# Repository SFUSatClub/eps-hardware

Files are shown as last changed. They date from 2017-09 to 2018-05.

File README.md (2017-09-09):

# CubeSat Electrical Power Subsystem
KiCad project of the cubesat electrical power subsystem test article in preparation for the Canadian Satellite Design Challenge

This repository uses the SFU Satellite Team's KiCad component library as a submodule.
To start working on the repository:

```
1. Open the git shell
2. Navigate to the directory you wish to place the repository inside
3. git clone --recursive "https://github.com/SFUSatClub/eps-hardware.git"
4. cd .\eps-hardware\KiCad-Lib\
5. git checkout master
```

If you modify either the component schematic or footprint libraries you must push those changes to the SFUSatClub/KiCad-Lib repository.

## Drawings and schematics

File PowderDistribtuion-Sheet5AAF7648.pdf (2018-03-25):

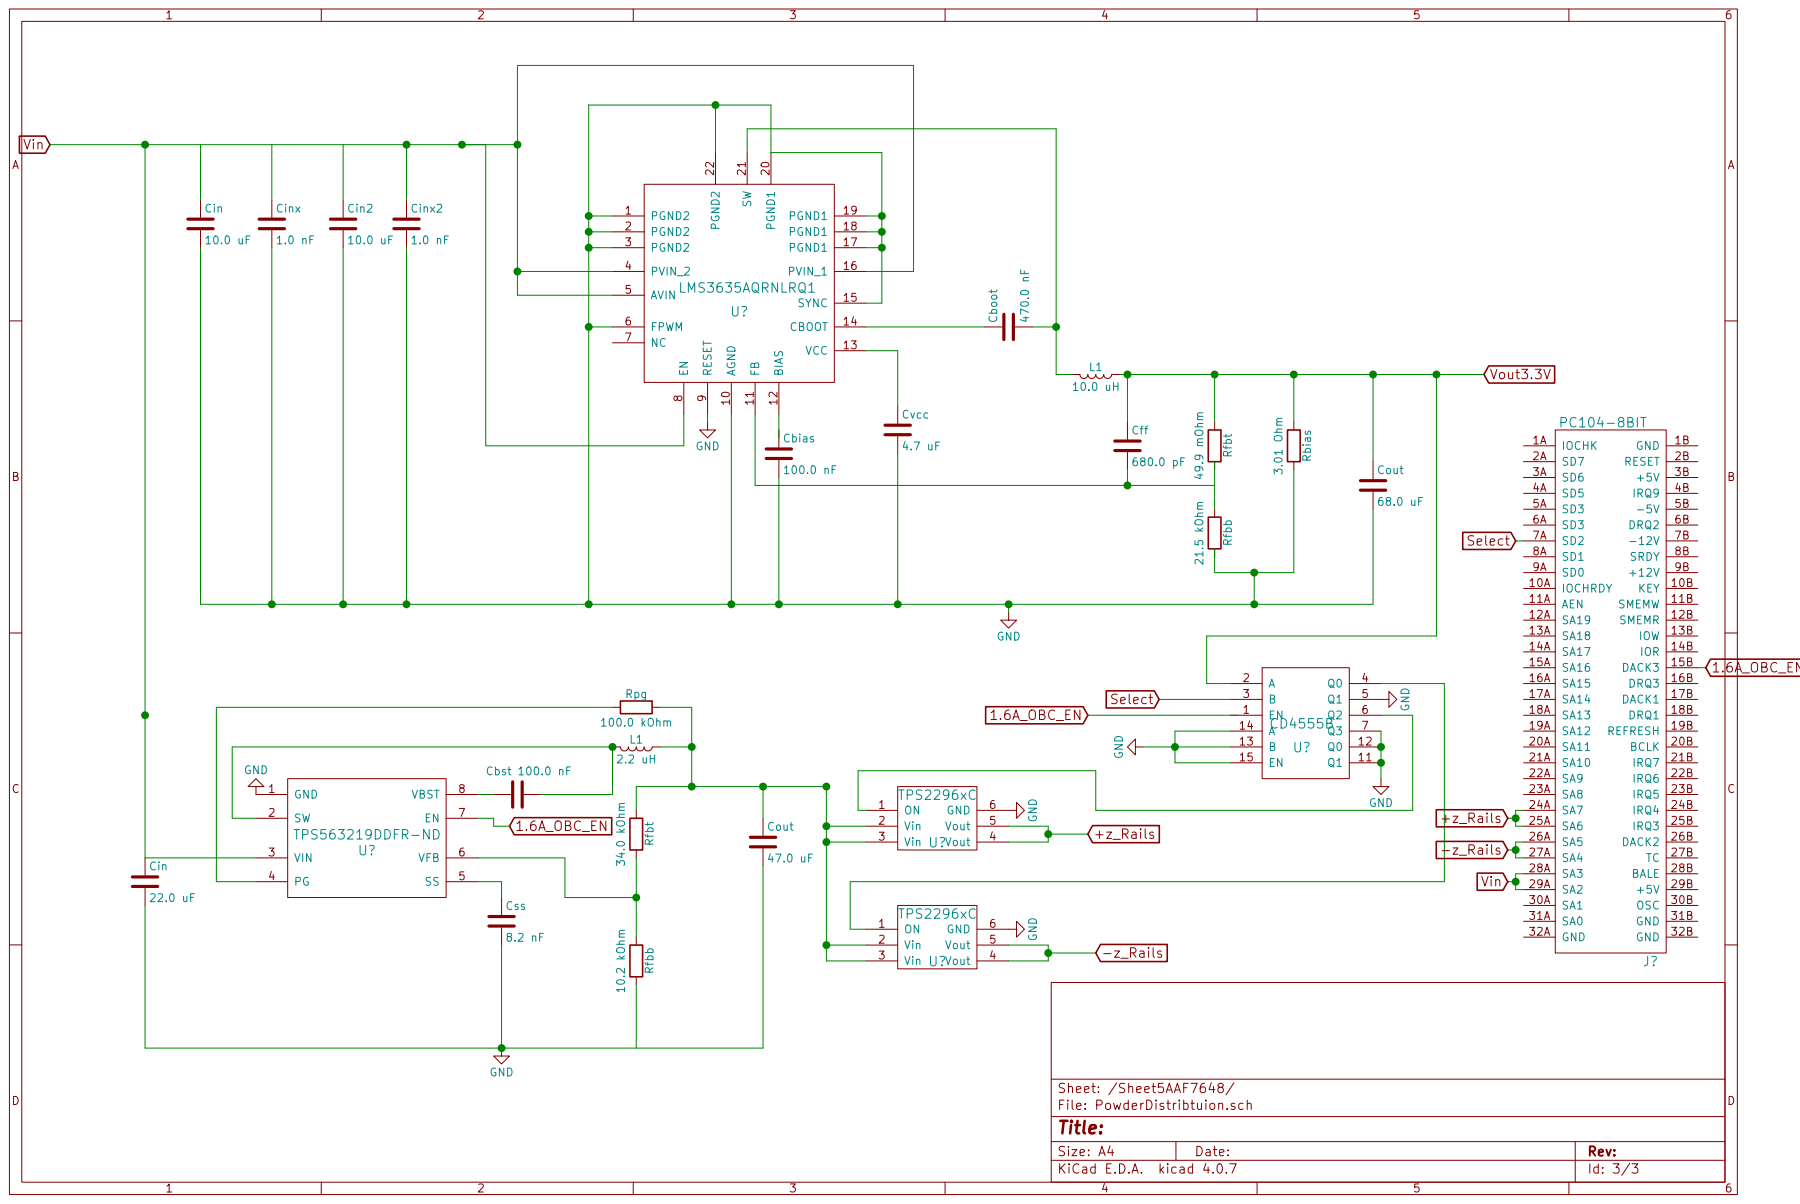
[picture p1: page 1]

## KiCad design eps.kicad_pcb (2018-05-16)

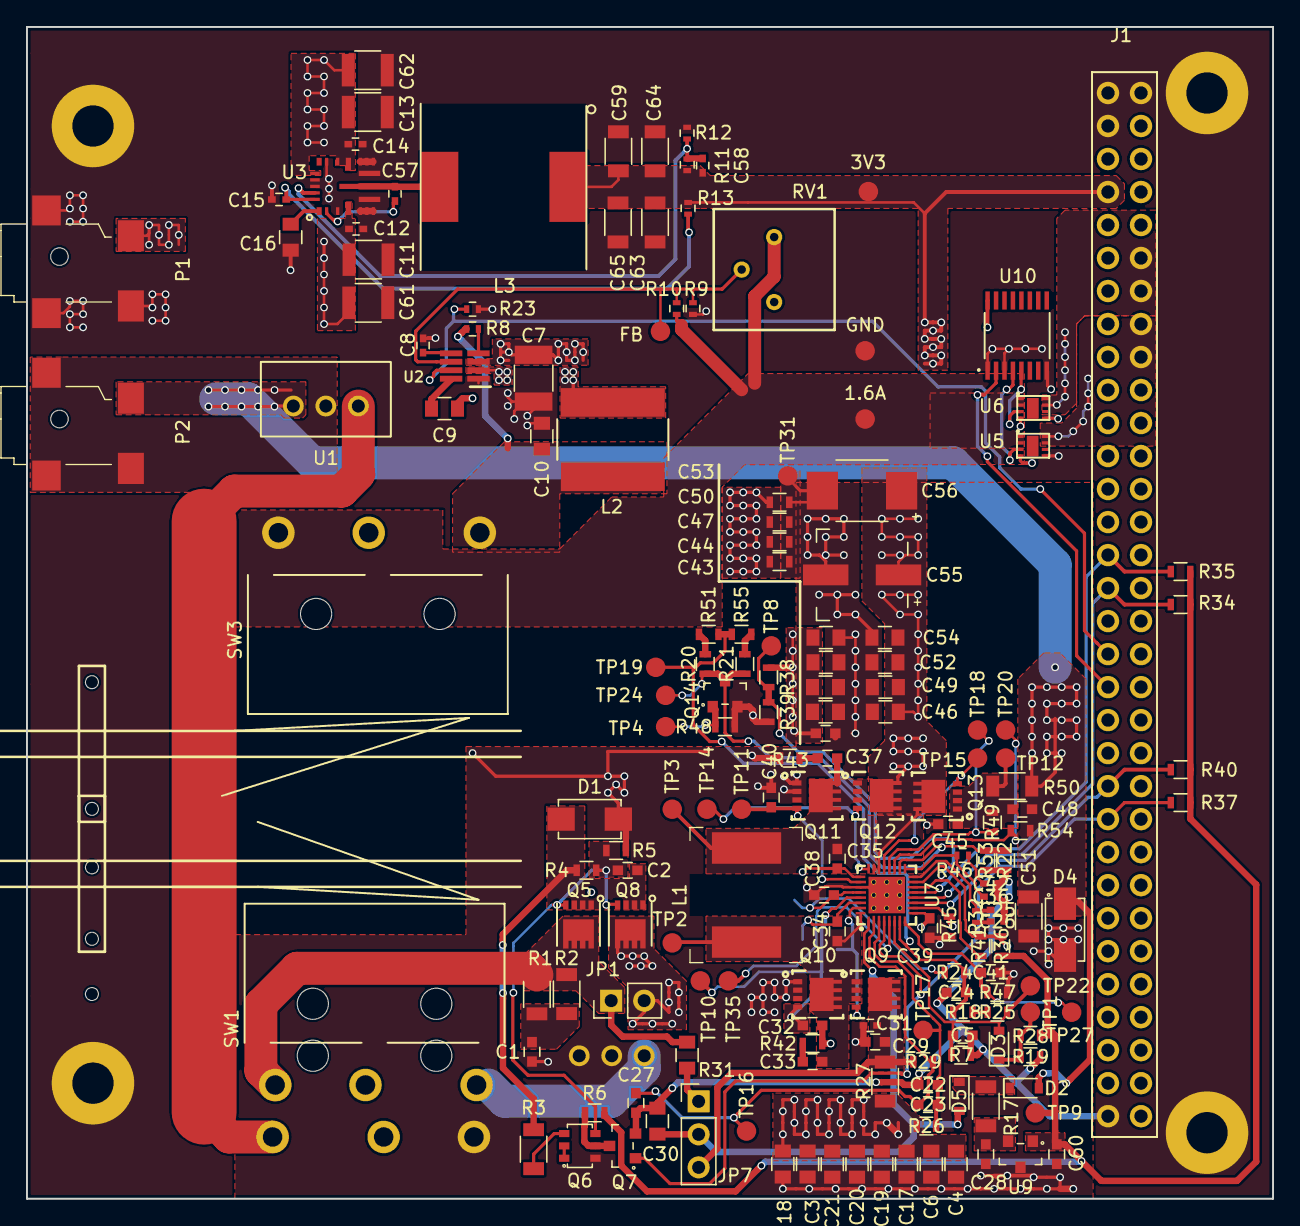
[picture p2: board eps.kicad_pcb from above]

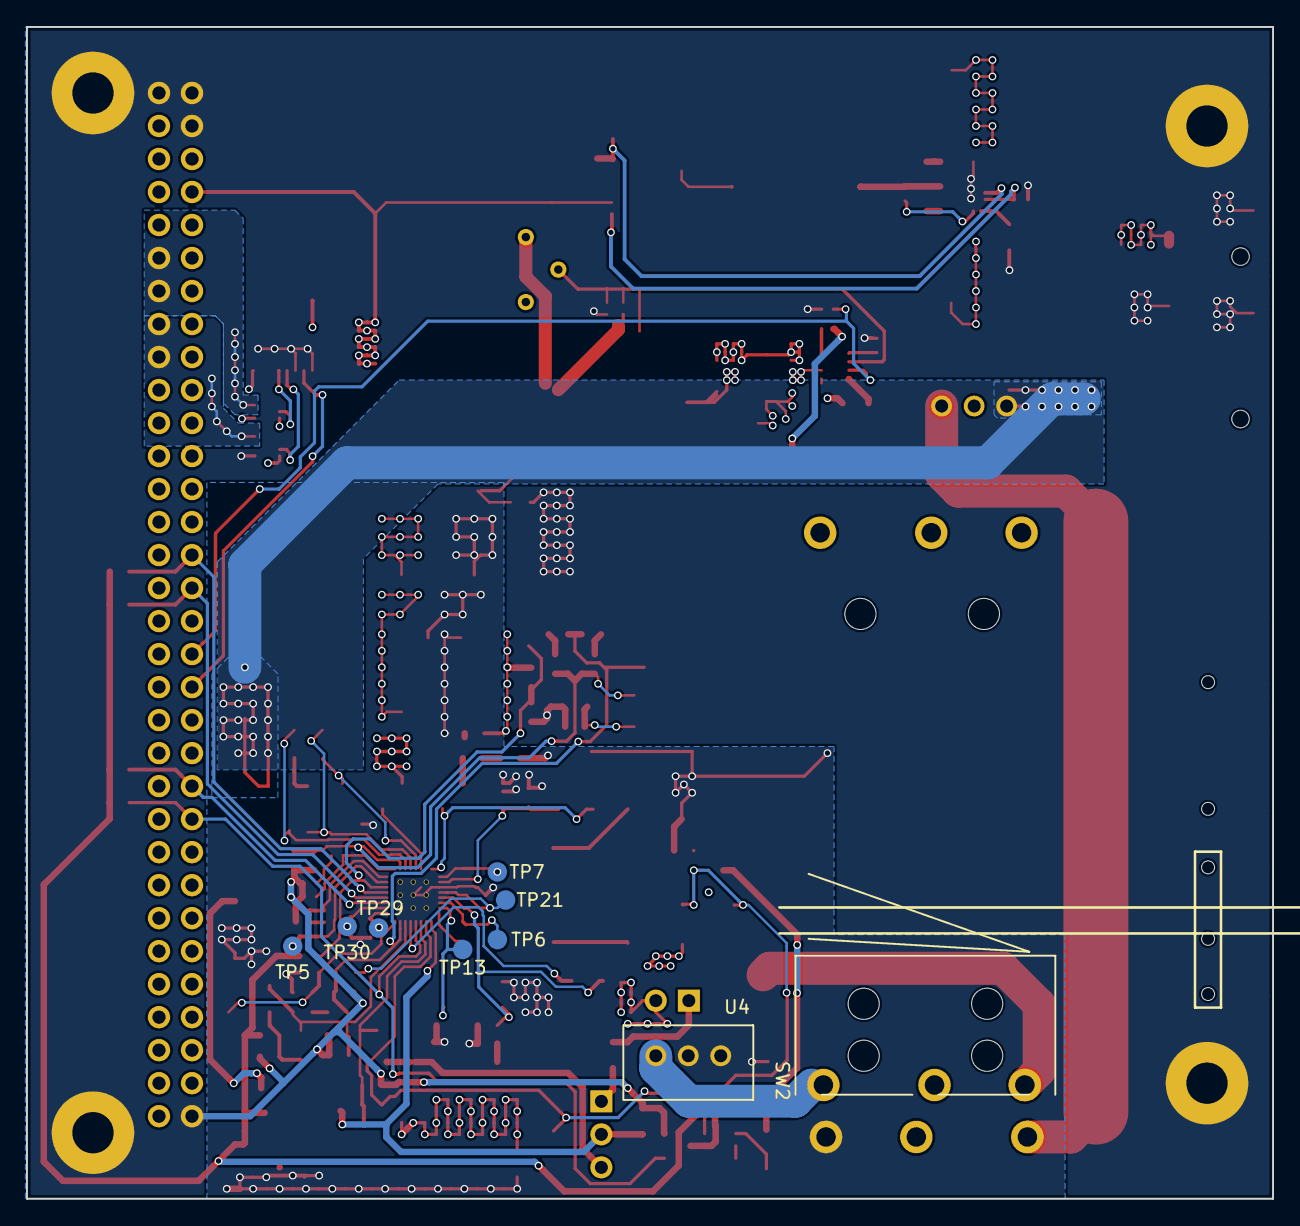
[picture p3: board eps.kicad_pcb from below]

Board: 4 copper layers, 95.9 x 90.2 mm, 189 parts (9 on the bottom side), 80 nets.

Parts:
C1, C24: 1u0; C_0603
C2, C28, C48, C60: 100n0; C_0603
C3, C18, C53, C54: DNP; C_0805
C4, C6, C17, C19, C20, C21: 10u0; C_0805
C5, C39, C41: 100p0; C_0603
C7: 22.0 uF; C_1210
C8: 8.2 nF; C_0402
C9: 100.0 nF; C_0805
C10: 47.0 uF; C_0805
C11, C13, C61, C62: 10.0 uF; C_1210
C12, C14: 1.0 nF; C_0402
C15: 100.0 nF; C_0402
C16: 4.7 uF; C_0805
C22, C27: 33n0; C_0603
C23, C33, C37, C43: DNP; C_0603
C25: 33p0; C_0402
C26: 1n8; C_0402
C29: 10n0; C_0603
C30: 470n0; C_0805
C31: 1n0; C_0402
C32, C40: 150p; C_0603
C34, C35: 47n; C_0603
C36: 15p0; C_0402
C38: 2u2; C_0603
C42: 680p; C_0402
C44, C46, C47, C49, C50, C52: 10u; C_0805
C45: 1u; C_0603
C51: 10u0; C_1206
C55: DNP; C_ALUM_2626
C56: 47u; C_TANT_2917
C57: 470.0 nF; C_0402
C58: 680.0 pF; C_0402
C59, C63, C64, C65: 68.0 uF; C_1206
D1: SMAJ26CA; DO-214AC-BI
D2, D3, D5: BAT54HT1G; SOD-323
D4: B220A-13-F; DO-214AC
J1: PC104-8BIT; PC104-8bit
J2, J3, J4, J5: PC104PTH
JP1: Conn_01x02; Socket_Strip_Straight_1x02_Pitch2.54mm
JP7: Conn_01x03; Socket_Strip_Straight_1x03_Pitch2.54mm
L1: 2u2; L_8030
L2: 2.2 uH; SRN8040-2R2Y
L3: 10.0 uH; L_7447709100
P1, P2: 3pin-DC-power; PJ-028-SMT-TR-3pin-DC-jack
Q5, Q8: DMP3035SFG-7; POWERDI3333-8
Q6: DCX124EK-7-F; SC-74
Q7, Q14: 2N7002ET1G; SOT-23-3
Q9, Q10, Q11, Q12: CSD17551Q3A; 8-PowerWDFN
Q13: CSD25402Q3A; 8-PowerWDFN
R1, R2: 3R9; R_1206
R3, R17: 10R0; R_1206
R4, R53: 100k0; R_0603
R5: 20k0; R_0603
R6, R36, R37, R40: 10k0; R_0603
R7: 220k0; R_0603
R8: 100k; R_0402
R9: DNP; R_0402
R10: 1k62; R_0402
R11: 49.9 kOhm; R_0402
R12: 21.5 kOhm; R_0402
R13: 3.01 Ohm; R_0402
R14, R15, R16, R19, R21, R22, R34, R35, R38, R42, R43, R44: DNP; R_0603
R18, R20: 0R; R_0603
R23: 1K; R_0402
R24, R49, R54: 10R0; R_0603
R25, R28: 383k0; R_0603
R26, R29: 4R99; R_0603
R27, R50: 10m0; R_1206
R31: 1R0; R_0805
R32: 40k2; R_0402
R39, R48: 300k0; R_0603
R41: 2M0; R_0603
R45: 30k1; R_0603
R46: 10k0; R_0402
R47: 137k0; R_0603
R51: 120k0; R_0603
R55: 64k9; R_0603
RV1: CT6EP103
SW1, SW2: LIMIT_SWITCH; SS-3GLPD-L
SW3: LIMIT_SWITCH; SS-3GLPD-R
TP1, TP2, TP3, TP4, TP5, TP6, TP7, TP8, TP9, TP10, TP11, TP12, TP13, TP14, TP15, TP16, TP17, TP18, TP19, TP20, TP21, TP22, TP23, TP24, TP25, TP27, TP28, TP29, TP30, TP31, TP33, TP35: TEST; Measurement_Point_Round-SMD-Pad_Small
U1, U4: B3B-XH-A(LF)(SN); B3B-XH-A
U2: TPS563219DDFR-ND; SOT-23-8
U3: LMS3635AQRNLRQ1; LMS3635AQRNLTQ1
U5, U6: TPS22967
U7: bq25703arsnt; S-PWQFN-N32
U9: LM3480; SOT-23-3
U10: CD4555BPWR; TSSOP-16

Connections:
/1.6A_Regulator_PDB/1.6A: C10.1, L2.1, R8.2, SW3.COM
/1.6A_Regulator_PDB/PG: R8.1, U2.4
/1.6A_Regulator_PDB/SW: C9.1, L2.2, U2.2
/1.6A_Regulator_PDB/VBOOT: C9.2, U2.8
/3.3V_Regulator_PDB/BIAS: C15.1, R13.2, U3.22
/3.3V_Regulator_PDB/CBOOT: C57.1, U3.2
/3.3V_Regulator_PDB/FB: C58.2, R11.2, R12.1, U3.21
/3.3V_Regulator_PDB/SW: C57.2, L3.2, U3.9
/3.3V_Regulator_PDB/VCC: C16.1, U3.1
/3V3: C58.1, C59.1, C63.1, C64.1, C65.1, J1.3B, J1.29B, L3.1, R11.1, R13.1, TP28.1, U5.4, U6.4, U10.16
/+z_rail: J1.24A, J1.25A, U5.7, U5.8
/-z_rail: J1.26A, J1.27A, U6.7, U6.8
/BMS/3V3: C60.1, R6.1, R28.1, R34.1, R35.1, R36.1, R37.1, R40.1, TP9.1, U9.1
/BMS/ACN: C23.2, C27.1, R29.2, TP16.1, U7.2
/BMS/ACP: C22.1, C23.1, R26.2, TP17.1, U7.3
/BMS/CELL_control: Q14.1, R48.2, TP4.1
/BMS/COMP2: C36.1, R46.1, U7.17
/BMS/HIDRV1: Q9.4, TP13.1, U7.31
/BMS/HIDRV2: Q12.4, TP14.1, U7.24
/BMS/ILIM_HIZ: C5.1, D3.1, R7.1, R25.1, TP22.1, U7.6
/BMS/ILIM_control: D3.2, R19.1, R28.2, TP1.1
/BMS/LODRV1: C32.1, Q10.4, TP10.1, U7.29
/BMS/LODRV2: C40.1, Q11.4, TP11.1, U7.26
/BMS/REGN: C38.1, R24.1, TP21.1, U7.28
/BMS/SRN: R54.2, TP20.1, U7.19
/BMS/SRP: R49.2, TP18.1, U7.20
/BMS/SW1: C33.1, C34.1, L1.1, Q9.1, Q9.2, Q9.3, Q10.5, Q10.6, Q10.7, Q10.8, Q10.9, TP2.1, U7.32
/BMS/SW2: C35.1, C37.1, L1.2, Q11.5, Q11.6, Q11.7, Q11.8, Q11.9, Q12.1, Q12.2, Q12.3, TP3.1, U7.23
/BMS/VBUS: C30.1, D5.1, JP7.2, U7.1
/BMS/VDDA: C24.1, R18.1, R24.2, R51.2, R55.2, TP19.1, U7.7
/BMS/VIN+: JP1.1, Q5.5, Q5.6, Q5.7, Q5.8, Q5.9, R1.1, R2.1, R31.2, SW1.NC
/CHG_OK: J1.10B, Q7.1, R37.2, U7.4
/DPL_EN: J1.15B, R23.1, U2.7
/DPL_SEL: J1.14B, U10.2
/FB: R9.2, R10.1, RV1.2, TP23.1, U2.6
/PowerDistributionDeploymentControl/1.6A: R9.1, RV1.1, SW3.NC, TP25.1, U5.1, U5.2, U6.1, U6.2
/PowerDistributionDeploymentControl/on+z: U5.3, U10.4
/PowerDistributionDeploymentControl/on-z: U6.3, U10.5
/SCL: J1.18B, R35.2, U7.13
/SDA: J1.17B, R34.2, U7.12
/VSYS_RETURN: C7.1, C11.1, C12.1, C13.1, C14.1, C61.1, C62.1, J1.28A, J1.29A, P1.1, U2.3, U3.4, U3.14, U3.15, U3.18
/VSYS_UP: C43.1, C44.1, C46.1, C47.1, C49.1, C50.1, C52.1, C53.1, C54.1, C55.1, C56.1, J1.30A, J1.31A, Q12.5, Q12.6, Q12.7, Q12.8, Q12.9, Q13.5, Q13.6, Q13.7, Q13.8, Q13.9, R38.1, U7.22
/Vin_Solar: SW1.COM, U4.3
/pack+: C48.2, C51.1, D2.1, D4.2, P2.1, R50.2, R54.1, U1.1
/pack-: P2.2, P2.3, U1.2
/return: SW2.COM, U1.3
/~PROCHP: J1.11B, R40.2, U7.11
GND: C5.2, C7.2, C8.2, C10.2, C11.2, C12.2, C13.2, C14.2, C15.2, C16.2, C22.2, C24.2, C25.1, C26.1, C27.2, C30.2, C36.2, C42.2, C59.2, C61.2, C62.2, C63.2, C64.2, C65.2, J1.1B, J1.31B, J1.32A, J1.32B, J2.1, J3.1, J4.1, J5.1, P1.2, P1.3, Q7.2, Q14.2, R7.2, R10.2, R12.2, R14.2, R15.2, R16.2, R19.2, R22.2, R23.2, R39.2, R44.2, R48.1, R53.1, TP33.1, U2.1, U3.3, U3.5, U3.6, U3.7, U3.8, U3.10, U3.11, U3.12, U3.13, U3.16, U3.19, U3.20, U5.5, U6.5, U10.1, U10.3, U10.8
GNDPWR: C1.2, C3.2, C4.2, C6.2, C17.2, C18.2, C19.2, C20.2, C21.2, C28.2, C29.2, C31.2, C32.2, C38.2, C39.2, C40.2, C41.2, C43.2, C44.2, C45.2, C46.2, C47.2, C49.2, C50.2, C51.2, C52.2, C53.2, C54.2, C55.2, C56.2, C60.2, D1.2, D4.1, Q6.6, Q10.1, Q10.2, Q10.3, Q11.1, Q11.2, Q11.3, R5.2, R14.1, R15.1, R16.1, R42.2, R43.2, R44.1, R45.1, R47.1, SW2.NC, TP31.1, U4.1, U4.2, U7.27, U7.33, U9.3
unnamed: C1.1, R1.2, R2.2
unnamed: C2.1, D1.1, Q5.1, Q5.2, Q5.3, Q8.1, Q8.2, Q8.3, R3.1, R4.1
unnamed: C2.2, Q5.4, Q6.4, Q8.4, R4.2, R5.1
unnamed: C8.1, U2.5
unnamed: C3.1, C4.1, C6.1, C17.1, C18.1, C19.1, C20.1, C21.1, JP1.2, Q8.5, Q8.6, Q8.7, Q8.8, Q8.9, R26.1, R27.1
unnamed: C25.2, R32.2, U7.16
unnamed: C26.2, R32.1
unnamed: C28.1, R17.2, U9.2
unnamed: C29.1, C31.1, JP7.3, Q9.5, Q9.6, Q9.7, Q9.8, Q9.9, R27.2, R29.1
unnamed: C33.2, R42.1
unnamed: C34.2, TP6.1, U7.30
unnamed: C35.2, TP7.1, U7.25
unnamed: C37.2, R43.1
unnamed: C39.1, TP29.1, U7.9
unnamed: C41.1, R47.2, TP27.1, U7.8
unnamed: C42.1, R46.2
unnamed: C45.1, C48.1, Q13.1, Q13.2, Q13.3, R49.1, R50.1, TP12.1
unnamed: D2.2, D5.2, R17.1
unnamed: JP7.1, R31.1
unnamed: Q6.1, Q6.2
unnamed: Q6.3, R3.2
unnamed: Q6.5, Q7.3, R6.2
unnamed: Q13.4, TP15.1, U7.21
unnamed: Q14.3, R20.2, R21.2, R22.1, R53.2, TP24.1, U7.18
unnamed: R18.2, R25.2
unnamed: R20.1, R51.1
unnamed: R21.1, R55.1
unnamed: R36.2, R41.1, TP5.1, U7.15
unnamed: R38.2, R39.1, R41.2, TP8.1, U7.14
unnamed: R45.2, TP30.1, U7.10
unnamed: TP35.1, U7.5

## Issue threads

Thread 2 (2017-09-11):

CubeSat side panel naming

TobiNakamura, 2017-09-11:
There are 4 solar battery charger schematics (MPPT_#) each numbered as 1,2,3,4. This name should be changed so that they are more descriptive of cubesat side. Something like port, starboard, topside, bottomside?

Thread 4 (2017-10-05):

Add Pull-before flight and deployment pins

TobiNakamura, 2017-10-05:
Series switches need to be placed to disconnect all solar cells and batteries.

TobiNakamura, 2018-02-07:
RBF needs to disconnect battery from ground and battery to load. Deployment pins are in series with RBF. The umbilical DC jack will need to use the jack switch feature to connect the battery with regulators while the RBF and/or deployment switches are engaged.

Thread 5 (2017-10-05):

bq40z50-R1 EOL

TobiNakamura, 2017-10-05:
confirm that bq40z50-R2 is a direct replacement: pin compatible, function near identical, performance near identical.

Alenux55, 2018-01-23:
This is getting replaced with [bq25703arsnt](https://www.digikey.ca/product-detail/en/texas-instruments/BQ25703ARSNT/296-46956-1-ND/7400157), is that correct?

TobiNakamura, 2018-01-24:
bq40z50-R2 is also being replaced by bq25703arsnt as @Alenux55 has noted.

Closed 2018-01-24.

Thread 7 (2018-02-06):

Battery Temp Sensing

TobiNakamura, 2018-02-06:
Need a thermal couple or similar on the batteries. OBC still has available I2C that could be used.

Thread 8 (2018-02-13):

New BMS, Mosfet symbol mismatch

Michael-Graves, 2018-02-13:
The schematic symbol for CSD25402Q3A is different from that of the datasheet.

On the datasheet (http://www.ti.com/lit/ds/symlink/csd25402q3a.pdf), the source is connected to the arrow while in our schematic the drain is connected to the arrow.

Michael-Graves, 2018-03-31:
The pin numbering is correct just the S and D labels are swapped

Closed 2018-05-04.

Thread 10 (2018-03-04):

Fix VSYS pin on BMS

Alenux55, 2018-03-04:
Currently, VSYS is connected to ground; obviously it should be connected to VSYS:

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

Alenux55, 2018-09-16:
This looks good to me now:
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

Closed 2018-09-16.

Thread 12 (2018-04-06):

SER2915L-103KL Footprint Issue

HarrisonHandley, 2018-04-06:
The downloaded footprint from Digikey for SER2915L-103KL Inductor doesn't agree exactly with the footprint layout in the datasheet. http://www.ti.com/lit/ds/symlink/cd4555b.pdf

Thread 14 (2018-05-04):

Power Mosfet footprints/netlists need to connect Pad 9 with pads 5-8

Michael-Graves, 2018-05-04:
The layout shouldn't need to be updated as fills are already in place, just need the netlists to be updated

Closed 2018-05-04.

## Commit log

2017-09-04 MPPT schematic complete. Following ST app note AN3319 section 5.
    [eps.sch]
2017-09-11 created MPPT hierarchical sheet
    [eps.sch, mppt.sch]
2017-09-11 added hierarchical sheet for BMS
    [bms.sch, eps.sch, mppt.sch]
2017-09-11 copied MPPT section for each of 4 side panels. The name for these 4 panels should be more descriptive
    [bms.sch, eps.sch, mppt.sch]
2017-09-12 overvoltage protection, charging/discharging fets, coloumb counter filter schematics complete. What should the secondary overvoltage output trigger? How should the MPPT output connect to the battery 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
    [bms.sch, eps.sch, mppt.sch]
2018-01-23 Started adding BQ25703ARSNT
    [BMS_new.sch, bms.sch, eps.kicad_pcb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]
2018-01-23 Fixed paste layer generation error. The global paste clearance layer set to -0.1mm cause some pads to not have a paste aperture generated in gerbers.
    [eps.kicad_pcb]
2018-02-05 Deleted MPPT curcuit. MPPT has been transfered to the panel-connector board
    [BMS_new.sch, bms.sch, eps.sch]
2018-02-06 Seriously starting the BMS schematic
    [BMS_new.sch, bms.sch, eps.sch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]
2018-02-09 Continued BMS schematic updates
    [BMS_new.sch]
2018-02-12 Added aluminum 47u cap
    [BMS_new.sch]
2018-02-13 Added some more BMS components
    [BMS_new.sch]
2018-02-13 Added Schematic for Series battery pack with balancer
    [BMS_new.sch, SeriesBatteryCell.sch, bms.sch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]
2018-02-13 Added schematic for the full 2s4p battery pack, added some of the components for the battery connection to the BMS
    [BMS_new.sch, BatteryPack.sch, SeriesBatteryCell.sch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]
2018-02-14 Replaced battery symbol from the device library with one from SFUSat-Power
    [BMS_new.sch, BatteryPack.sch, SeriesBatteryCell.sch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]
2018-02-16 Added more BMS-new components
    [BMS_new.sch]
2018-02-18 moved series battery symbol to SFUSat lib
    [SeriesBatteryCell.sch]
2018-02-18 Continued BMS_new.sch work
    [BMS_new.sch, eps.sch]
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2018-02-21 Pretty much done BMS_new
    [BMS_new.sch, BatteryPack.sch, SeriesBatteryCell.sch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]
2018-02-21 Fixed output of BMS_new
    [BMS_new.sch, SeriesBatteryCell.sch]
2018-03-10 added DC jack and made 3d model
    [BMS_new.sch, BatteryPack.sch, SeriesBatteryCell.sch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]
2018-03-10 added 3d models for the largest cap and inductor
    [eps.kicad_pcb]
2018-03-11 added deployment switches and DC jacks
    [BMS_new.sch, SeriesBatteryCell.sch, eps.kicad_pcb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]
2018-03-18 deleted batteries and changed BMS_new name
    [BMS.sch, BatteryPack.sch, SeriesBatteryCell.sch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]
2018-03-25 Including PDB schematics and components for 3.3V and 1.6A regulators
    [1.6ARailDeployment.sch, BMS.sch, PowderDistribtuion.sch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]
2018-03-25 Seperated PCB Components into schematic format
    [_saved_BMS.sch, eps.kicad_pcb]
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2018-03-30 fixed rescue components and missing schematic issues
    [_saved_BMS.sch, eps.sch]
2018-03-30 cleaned up sheets and heirarchical pins. Also added test points and connectors to BMS scheet
    [1.6ARailDeployment.sch, BMS.sch, PowerDistributionCurrent.sch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]
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2018-03-30 i dont know what i changed
    [eps.kicad_pcb]
2018-03-31 moved libraries around. See commits in Kicad-Lib
    [PowderDistribtuion.sch, eps.sch]
2018-03-31 replaced 0.1inch jumpers with SMT jumpers, made board 4 layers
    [1.6ARailDeployment.sch, BMS.sch, PowderDistribtuion.sch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]
2018-04-01 Started laying out the components, spacings and positions are temporary most are just placed relative to their locations in the schematic
    [1.6ARailDeployment.sch, PowderDistribtuion.sch, PowerDistributionCurrent.sch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]
2018-04-01 fixed demultiplexer
    [1.6ARailDeployment.sch, BMS.sch, PowderDistribtuion.sch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]
2018-04-06 Fixed Miscellanious Errors in PDB Portion
    Fixed Inductor SER2915L and small issues with footprints and pins for
    PDB Components.
    [1.6ARailDeployment.sch]
2018-04-06 Fixed TPS22964xC IC Pins
    [PowerDistributionCurrent.sch, eps.kicad_pcb]
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2018-04-22 Placed the Power Distribution Circuits on the PCB
    Includes traces rated for 2A.
    [BMS.sch, eps.kicad_pcb, eps.sch]
2018-04-22 Layed Out the Limit Switch Connections
    Inputs from limit switches for the BMS have been created and traced out.
    Only implementation left is the BMS then connections from the BUS
    [BMS.sch, PowerDistributionCurrent.sch, eps.kicad_pcb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]
2018-04-27 Attempt 2 at laying out 3.3V and 1.6A PD
    [PowderDistribtuion.sch, eps.kicad_pcb]
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2018-05-02 Working on BQ25703a, shrunk 1.6A regulator
    [eps.kicad_pcb]
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2018-05-03 Updataed demuxes on 1.6A distriution
    [1.6ARailDeployment.sch, eps.kicad_pcb, eps.sch]
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2018-05-03 All the components are on the board, phew
    [1.6ARailDeployment.sch, PowderDistribtuion.sch, PowerDistributionCurrent.sch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]
2018-05-04 Finished layout, needs DRZ check and to be reviewed
    [BMS.sch, eps.kicad_pcb]
2018-05-04 removed duplicate GND fill on bottom layer
    [eps.kicad_pcb]
2018-05-04 Split GND fills on Top and Bottom layers to match internal GND layer, fixed some fill priority issues, reduced some of the excessive vias :(.
    [eps.kicad_pcb]
2018-05-04 Fix pitch on U3 pins 5,6,12,13
    [eps.kicad_pcb]
2018-05-04 Fixed #8 and Fixed #14 officially and put correct footprints into layout. Needs to be fixed (specifically VSYS pin of the BMS needs to be connected)
    [BMS.sch, eps.kicad_pcb]
2018-05-04 attempting to fix things
    [_saved_BMS.sch]
2018-05-05 imporved polygons, connected DPL_EN
    [1.6ARailDeployment.sch, BMS.sch, PowderDistribtuion.sch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]
2018-05-05 added pull down on deployment enable pin incase the OBC output is undefined
    [1.6ARailDeployment.sch, BMS.sch, PowderDistribtuion.sch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]
2018-05-05 Fix Q6 footprint and redo traces
    [eps.kicad_pcb]
2018-05-06 Fixed Q6 routing
    [eps.kicad_pcb]
2018-05-10 Fix switch footprint terminal spacing and adjust track ends accordingly
    [eps.kicad_pcb]
2018-05-10 Move pads closer together on C56 footprint
    [eps.kicad_pcb]
2018-05-11 Update D4 pad dimensions and spacing to patch datasheet, regenerate pours
    [eps.kicad_pcb]
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2018-05-12 resolved fill related errors
    [eps.kicad_pcb]
2018-05-12 reanamed nets to make layout easier
    [1.6ARailDeployment.sch, BMS.sch, PowderDistribtuion.sch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]
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2018-05-14 improved high current traces
    [1.6ARailDeployment.sch, BMS.sch, PowderDistribtuion.sch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]
2018-05-16 added adjustible feedback for 1.6 a regulator. The point where the feedback taps off moved to after the RBF switch for better control
    [1.6ARailDeployment.sch, BMS.sch, PowderDistribtuion.sch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]
2018-05-16 simplified polygons, added holes for pin guides, added testpoints for power nets
    [BMS.sch, PowderDistribtuion.sch, PowerDistributionCurrent.sch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]
2018-05-16 modified FB pot config
    [eps-B.Cu.gbr, eps-B.Mask.gbr, eps-B.SilkS.gbr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]

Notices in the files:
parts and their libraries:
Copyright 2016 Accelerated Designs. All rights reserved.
